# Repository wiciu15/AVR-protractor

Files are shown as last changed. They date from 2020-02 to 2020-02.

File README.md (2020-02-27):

# AVR-protractor
ATMega8 based protractor with SSD1306 OLED and LIS3DH accelerometer.

Schematic and PCB made in KiCAD. Firmware project created in Atmel Studio 7. Makefile available.

Known issue - ISP header is flipped, don't try to connect it to AVRISP with kanda ribbon cable, it's gonna make a short.

Firmware is working, but some extra features are still WIP (@TODO in main.c)

Display driver made by @tibounise (https://github.com/tibounise/SSD1306-AVR) slightly modified by me to save RAM for framebuffer.

3d front

3d PCB

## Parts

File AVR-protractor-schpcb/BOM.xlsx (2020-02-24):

Source: | C:\Users\wiki1\Documents\kicad\Poziomica 1.0\Poziomica 1.0.sch
Date: | 2019-01-20 01:33
Tool: | Eeschema (5.0.2)-1
Generator: | C:\Program Files\KiCad\bin\scripting\plugins/bom_csv_grouped_by_value.py
Component Count: | 31
Collated Components:
Item | Qty | Reference(s) | Value | LibPart | Footprint | zamowiony | kupiony | doszedl | Cena/szt | Cena/PCB
1 | 1 | AC1 | LIS3DHTR | SamacSys_Parts:LIS3DHTR | SSD1306:LIS3DH | kamami | 1.00 | 1.00 | 4.90 | 4.90 zł
2 | 1 | BT1 | Battery | Device:Battery | SSD1306:1021BatteryAAA | allegro-sm | 1.00 |  | 3.00 | 3.00 zł
3 | 2 | C1, C2 | 12pF | Device:CP_Small | Capacitor_SMD:C_0805_2012Metric_Pad1.15x1.40mm_HandSolder | allegro-sm | 1.00 |  | 0.05 | 0.10 zł
4 | 8 | C3, C4, C5, C6, C7, C8, C9, C10 | 2,2uF | Device:CP_Small | Capacitor_SMD:C_0805_2012Metric_Pad1.15x1.40mm_HandSolder | allegro-sm | 1.00 |  | 0.05 | 0.40 zł
5 | 2 | C11, C12 | .1uF | Device:CP_Small | Capacitor_SMD:C_0603_1608Metric_Pad1.05x0.95mm_HandSolder | allegro-sm | 1.00 |  | 0.05 | 0.10 zł
6 | 2 | C13, C14 | 10uF | Device:CP_Small | Capacitor_SMD:C_0805_2012Metric_Pad1.15x1.40mm_HandSolder | allegro-sm | 1.00 |  | 0.05 | 0.10 zł
7 | 1 | CON1 | SSD 1306 OLED | SSD1306:OLED | SSD1306:SSD1306 | allegro artronic | 1.00 | 1.00 | 19.40 | 19.40 zł
8 | 1 | IC1 | MCP1623T-I_CHY | SamacSys_Parts:MCP1623T-I_CHY | SamacSys_Parts:SOT95P270X145-6N | tme | 1.00 | 1.00 | 2.16 | 2.16 zł
9 | 1 | J1 | Conn_02x05_Odd_Even | Connector_Generic_MountingPin:Conn_02x05_Odd_Even_MountingPin | SSD1306:PROG | w domu | 1.00 | 1.00 | 0.30 | 0.30 zł
10 | 1 | L1 | DLG-0403-4R7 | Device:L | SSD1306:IND-B82462G4 | allegro-sm | 1.00 |  | 2.46 | 2.46 zł
11 | 4 | R1, R2, R3, R4 | 10k | Device:R | Resistor_SMD:R_0805_2012Metric_Pad1.15x1.40mm_HandSolder | allegro-sm | 1.00 |  | 0.05 | 0.20 zł
12 | 1 | R5 | 120k | Device:R_Small | Resistor_SMD:R_1206_3216Metric_Pad1.42x1.75mm_HandSolder | allegro-sm | 1.00 |  | 0.05 | 0.05 zł
13 | 1 | R6 | 820k | Device:R | Resistor_SMD:R_0805_2012Metric_Pad1.15x1.40mm_HandSolder | allegro-sm | 1.00 |  | 0.05 | 0.05 zł
14 | 1 | R7 | 470k | Device:R | Resistor_SMD:R_0805_2012Metric_Pad1.15x1.40mm_HandSolder | allegro-sm | 1.00 |  | 0.05 | 0.05 zł
15 | 1 | SW1 | PWR | Switch:SW_Push | SamacSys_Parts:7914J1000E | allegro-sm | 1.00 |  | 1.23 | 1.23 zł
16 | 1 | SW2 | ZERO | Switch:SW_Push | SamacSys_Parts:7914J1000E | allegro-sm | 1.00 |  | 1.23 | 1.23 zł
17 | 1 | U1 | ATmega8A-AU | MCU_Microchip_ATmega:ATmega8A-AU | Package_QFP:TQFP-32_7x7mm_P0.8mm | allegro-artronic | 1.00 | 1.00 | 4.50 | 4.50 zł
18 | 1 | Y1 | Crystal | Device:Crystal | SSD1306:Crystal_HC49-U_Vertical | allegro-artronic | 1.00 | 1.00 | 0.50 | 0.50 zł
 |  |  |  |  |  |  |  |  |  | 40.73 zł

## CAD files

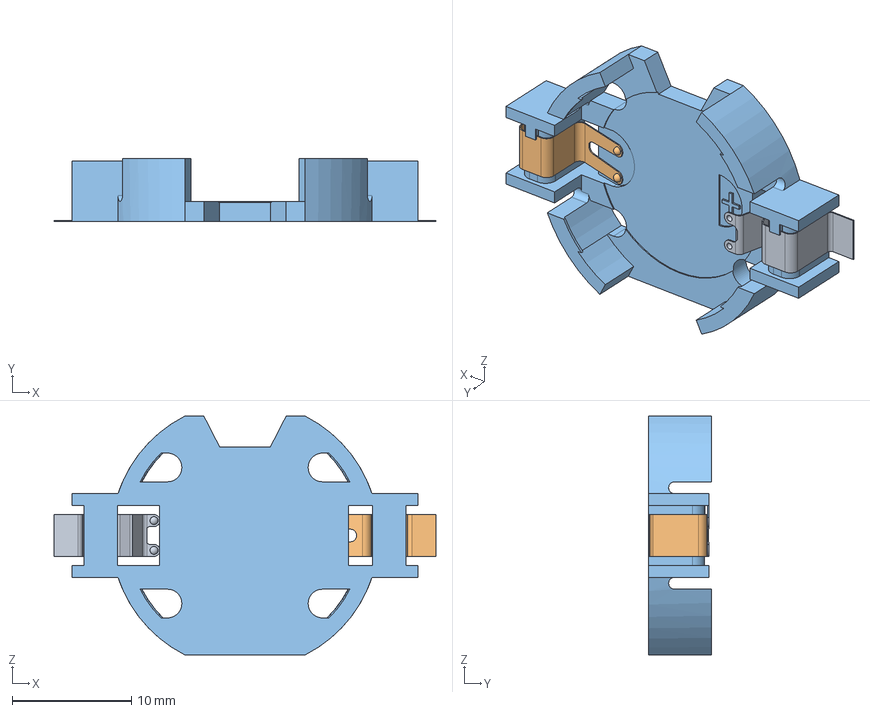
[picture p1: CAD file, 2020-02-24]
AVR-protractor-schpcb/CR2032/BU2032SM-HD-GCR2032 Battery Holder.stp
32.0 x 5.30 x 20.0 mm

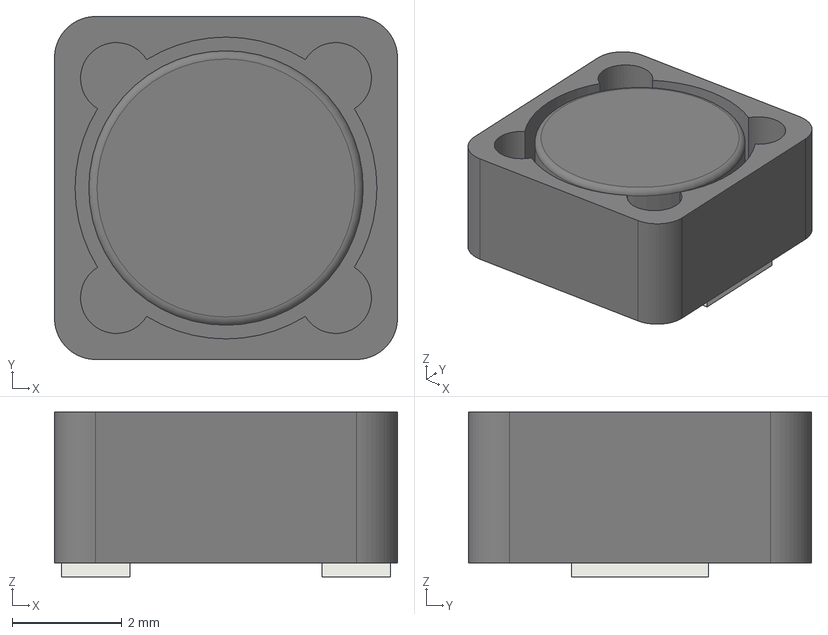
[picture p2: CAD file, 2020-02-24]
AVR-protractor-schpcb/L_Bourns_SRR1260 v1.step
6.25 x 6.25 x 3.00 mm

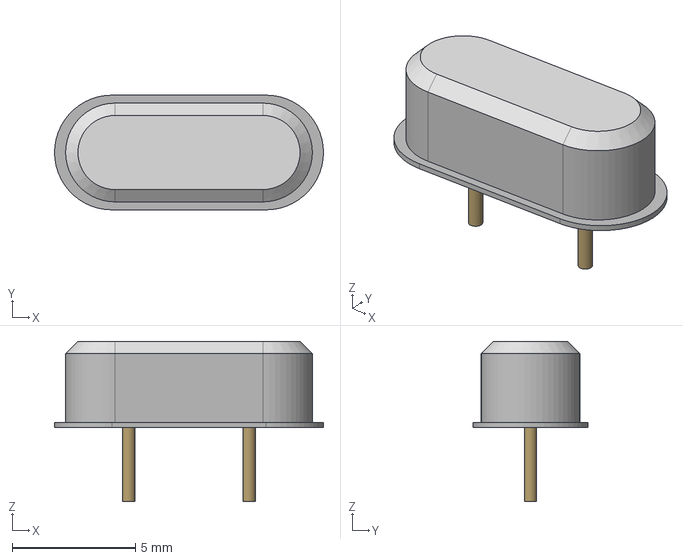
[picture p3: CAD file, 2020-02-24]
AVR-protractor-schpcb/Crystal_HC49-U_Vertical v2.step
10.9 x 4.65 x 6.50 mm

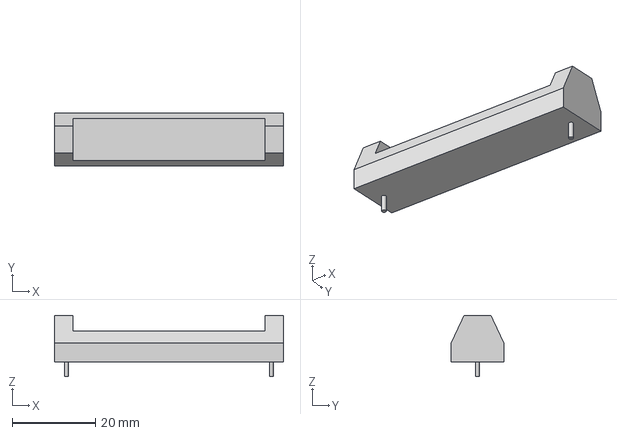
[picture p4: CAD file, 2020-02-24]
AVR-protractor-schpcb/Poziomica 1.0_battery v2.step
55.0 x 12.7 x 14.7 mm

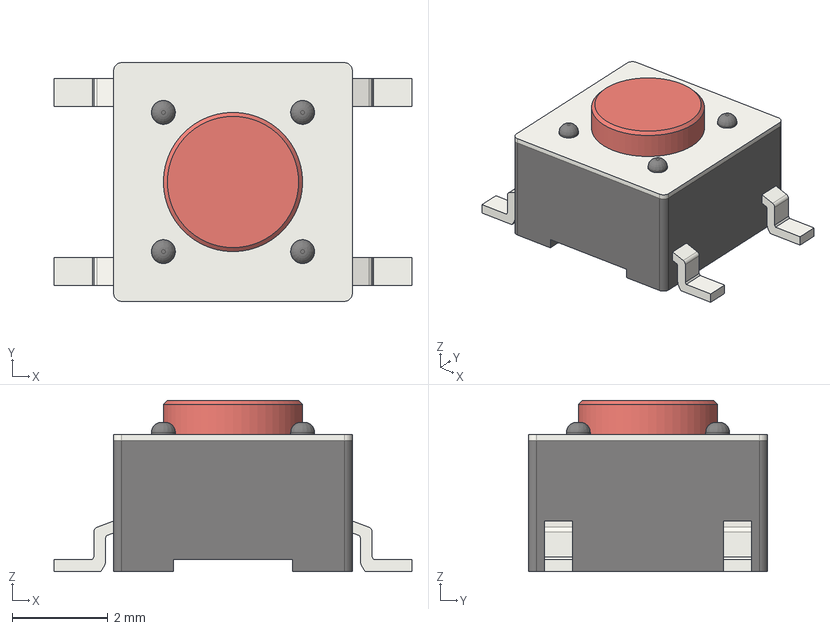
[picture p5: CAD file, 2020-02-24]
AVR-protractor-schpcb/SW_SPST_PTS645 v2.step
7.49 x 5.00 x 3.58 mm

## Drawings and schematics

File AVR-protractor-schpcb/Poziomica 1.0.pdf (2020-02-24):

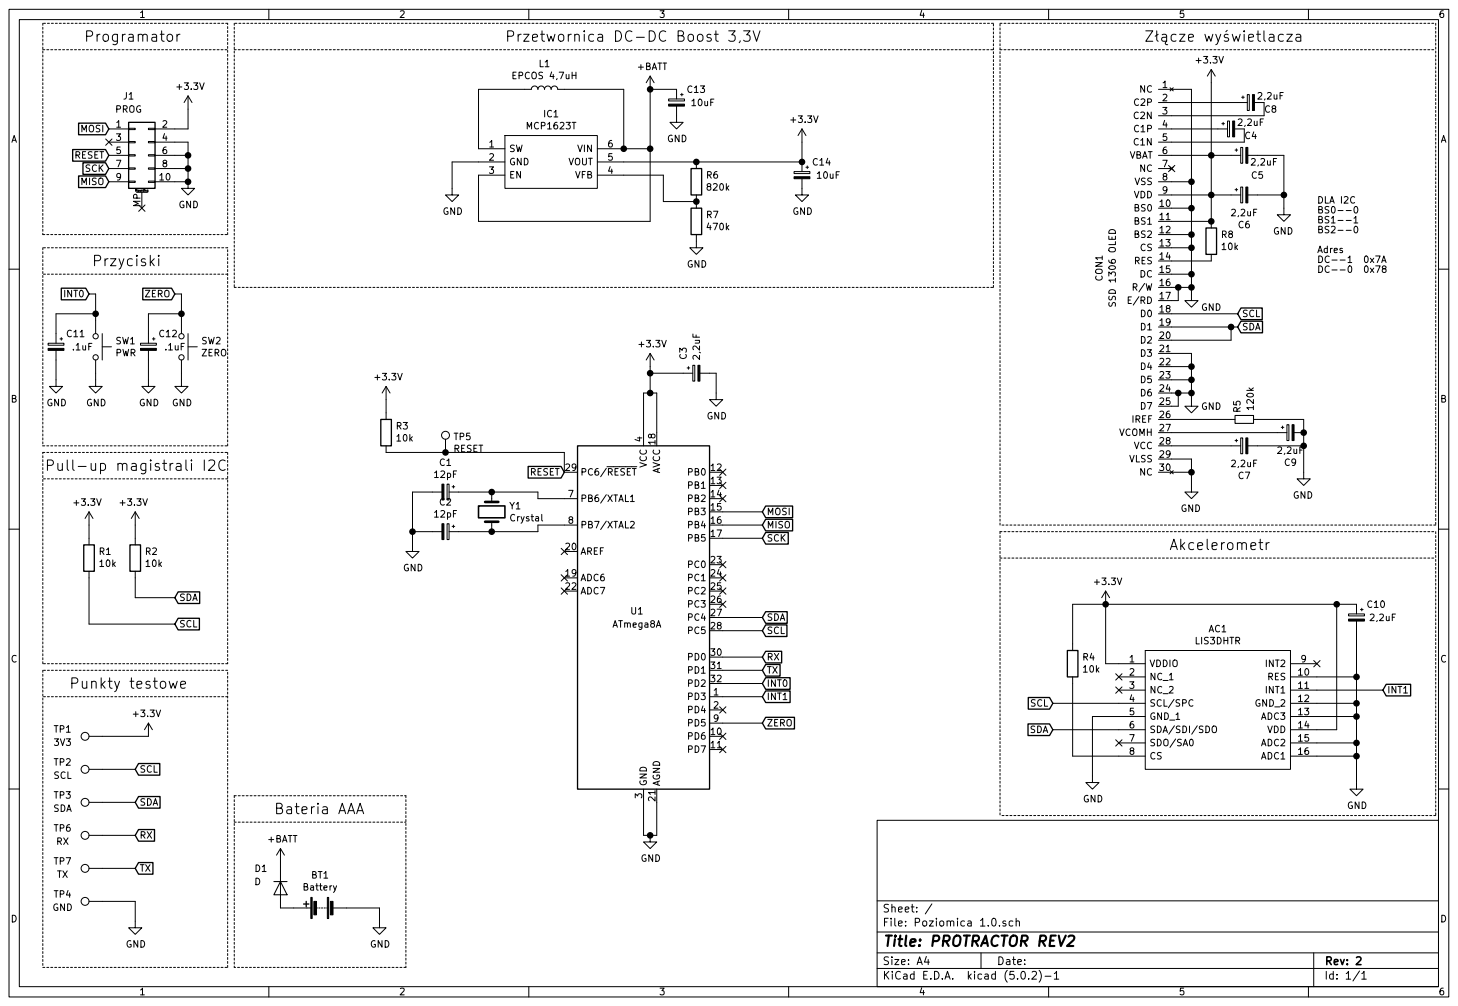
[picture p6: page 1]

Przetwornica DC-DC Boost 3,3V

NC 1 BS0 10 BS1 11 BS2 12 CS 13 RES 14 DC 15 R/W 16 E/RD 17 D0 18 D1 19 C2P 2 D2 20 D3 21 D4 22 D5 23 D6 24 D7 25
IREF 26 VCOMH 27 VCC 28 VLSS 29 C2N 3 NC 30 C1P 4 C1N 5 VBAT 6 NC 7 VSS 8 VDD 9 CON1 SSD 1306 OLED
Adres DC--1 0x7A DC--0 0x78 GND

J1 PROG MOSI RESET SCK MISO

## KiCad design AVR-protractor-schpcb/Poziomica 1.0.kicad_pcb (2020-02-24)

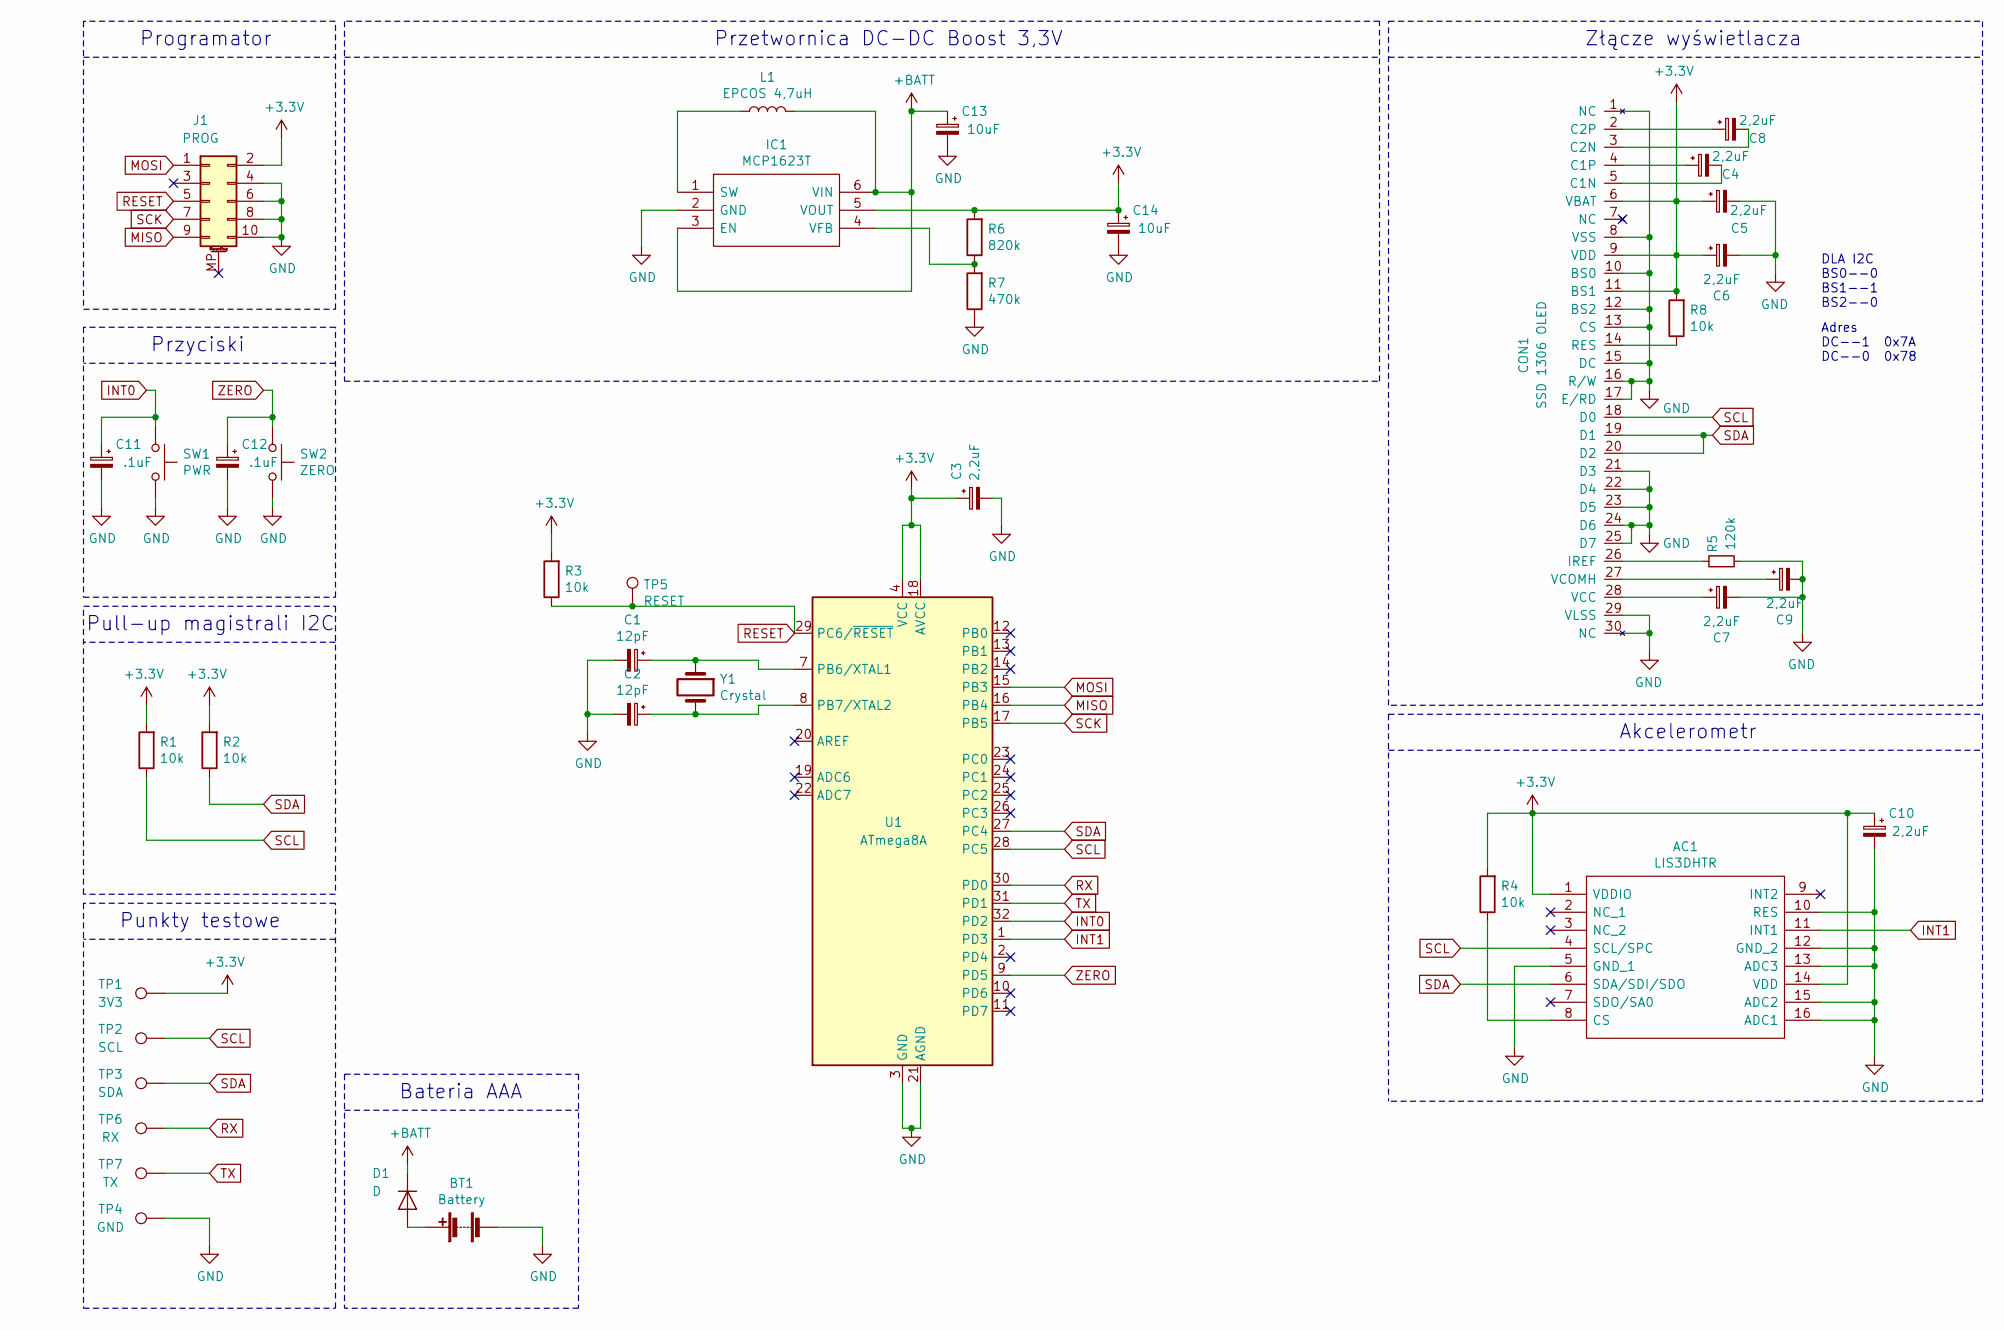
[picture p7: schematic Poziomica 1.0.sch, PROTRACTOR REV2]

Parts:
AC1: LIS3DHTR; LIS3DH_BigPad; Mouser Part Number 511-LIS3DHTR
BT1: Battery; 1021BatteryAAA
C1, C2: 12pF; C_0805_2012Metric_Pad1.15x1.40mm_HandSolder
C3, C4, C5, C6, C7, C8, C9, C10: 2,2uF; C_0805_2012Metric_Pad1.15x1.40mm_HandSolder
C11, C12: .1uF; C_0603_1608Metric_Pad1.05x0.95mm_HandSolder
C13, C14: 10uF; C_0805_2012Metric_Pad1.15x1.40mm_HandSolder
CON1: SSD 1306 OLED; SSD1306
D1: D; D_SOT-23_ANK
IC1: MCP1623T; SOT95P270X145-6N; Mouser Part Number 579-MCP1623T-I/CHY
J1: PROG
L1: EPCOS 4,7uH; IND-B82462G4
R1, R2, R3, R4, R8: 10k; R_0805_2012Metric_Pad1.15x1.40mm_HandSolder
R5: 120k; R_1206_3216Metric_Pad1.42x1.75mm_HandSolder
R6: 820k; R_0805_2012Metric_Pad1.15x1.40mm_HandSolder
R7: 470k; R_0805_2012Metric_Pad1.15x1.40mm_HandSolder
SW1: PWR; 7914J1000E
SW2: ZERO; 7914J1000E
TP1: 3V3; TestPoint_Pad_D2.0mm
TP2: SCL; TestPoint_Pad_D2.0mm
TP3: SDA; TestPoint_Pad_D2.0mm
TP4: GND; TestPoint_Pad_D2.0mm
TP5: RESET; TestPoint_Pad_D2.0mm
TP6: RX; TestPoint_Pad_D2.0mm
TP7: TX; TestPoint_Pad_D2.0mm
U1: ATmega8A; TQFP-32_7x7mm_P0.8mm
Y1: Crystal; Crystal_HC49-U_Vertical

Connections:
+3V3: AC1.1 (VDDIO), AC1.14 (VDD), C3.1, C5.1, C6.1, C10.1, C14.1, CON1.6 (VBAT), CON1.9 (VDD), CON1.11 (BS1), IC1.5 (VOUT), J1.2, R1.2, R2.2, R3.2, R4.2, R6.2, R8.2, TP1.1, U1.4 (VCC), U1.6 (VCC), U1.18 (AVCC)
+BATT: C13.1, D1.1 (K), IC1.3 (EN), IC1.6 (VIN), L1.2
GND: AC1.5 (GND_1), AC1.10 (RES), AC1.12 (GND_2), AC1.13 (ADC3), AC1.15 (ADC2), AC1.16 (ADC1), BT1.2 (-), C1.2, C2.2, C3.2, C5.2, C6.2, C7.2, C9.2, C10.2, C11.2, C12.2, C13.2, C14.2, CON1.1 (NC), CON1.8 (VSS), CON1.10 (BS0), CON1.12 (BS2), CON1.13 (CS), CON1.15 (DC), CON1.16 (R/W), CON1.17 (E/RD), CON1.21 (D3), CON1.22 (D4), CON1.23 (D5), CON1.24 (D6), CON1.25 (D7), CON1.29 (VLSS), CON1.30 (NC), IC1.2 (GND), J1.4, J1.6, J1.8, J1.10, R5.1, R7.1, SW1.2, SW2.2, TP4.1, U1.3 (GND), U1.5 (GND), U1.21 (AGND)
INT0: C11.1, SW1.1, U1.32 (PD2)
INT1: AC1.11 (INT1), U1.1 (PD3)
MISO: J1.9, U1.16 (PB4)
MOSI: J1.1, U1.15 (PB3)
unnamed: AC1.8 (CS), R4.1
unnamed: BT1.1 (+), D1.2 (A)
unnamed: C1.1, U1.7 (PB6/XTAL1), Y1.1
unnamed: C2.1, U1.8 (PB7/XTAL2), Y1.2
unnamed: C4.1, CON1.4 (C1P)
unnamed: C4.2, CON1.5 (C1N)
unnamed: C7.1, CON1.28 (VCC)
unnamed: C8.1, CON1.2 (C2P)
unnamed: C8.2, CON1.3 (C2N)
unnamed: C9.1, CON1.27 (VCOMH)
unnamed: CON1.14 (RES), R8.1
unnamed: CON1.26 (IREF), R5.2
unnamed: IC1.1 (SW), L1.1
unnamed: IC1.4 (VFB), R6.1, R7.2
RESET: J1.5, R3.1, TP5.1, U1.29 (PC6/~RESET)
RX: TP6.1, U1.30 (PD0)
SCK: J1.7, U1.17 (PB5)
SCL: AC1.4 (SCL/SPC), CON1.18 (D0), R1.1, TP2.1, U1.28 (PC5)
SDA: AC1.6 (SDA/SDI/SDO), CON1.19 (D1), CON1.20 (D2), R2.1, TP3.1, U1.27 (PC4)
TX: TP7.1, U1.31 (PD1)
ZERO: C12.1, SW2.1, U1.9 (PD5)

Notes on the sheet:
DLA I2C BS0--0 BS1--1 BS2--0
Złącze wyświetlacza
Akcelerometr
Punkty testowe
Pull-up magistrali I2C
Przyciski
Programator
Bateria AAA
Przetwornica DC-DC Boost 3,3V
Adres DC--1 0x7A DC--0 0x78

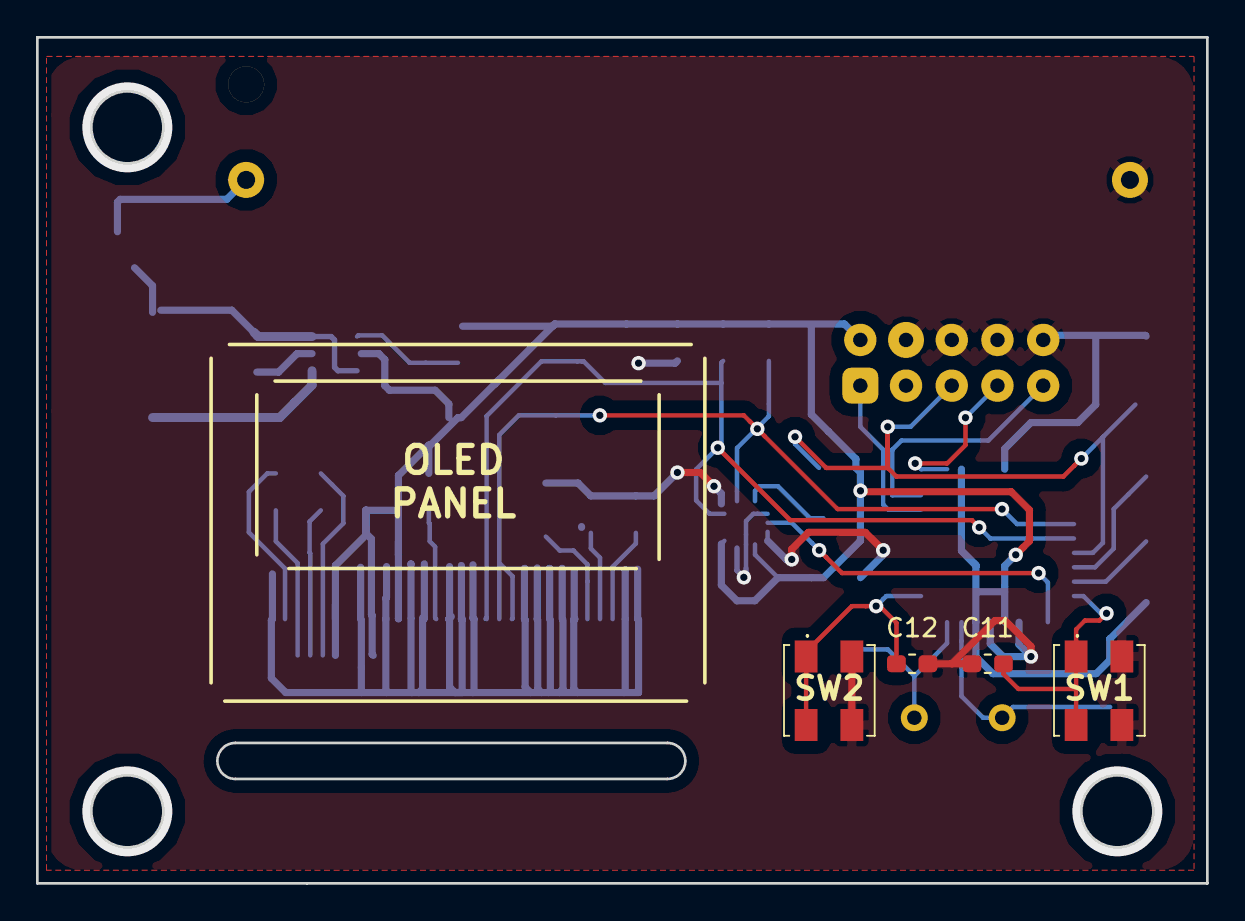
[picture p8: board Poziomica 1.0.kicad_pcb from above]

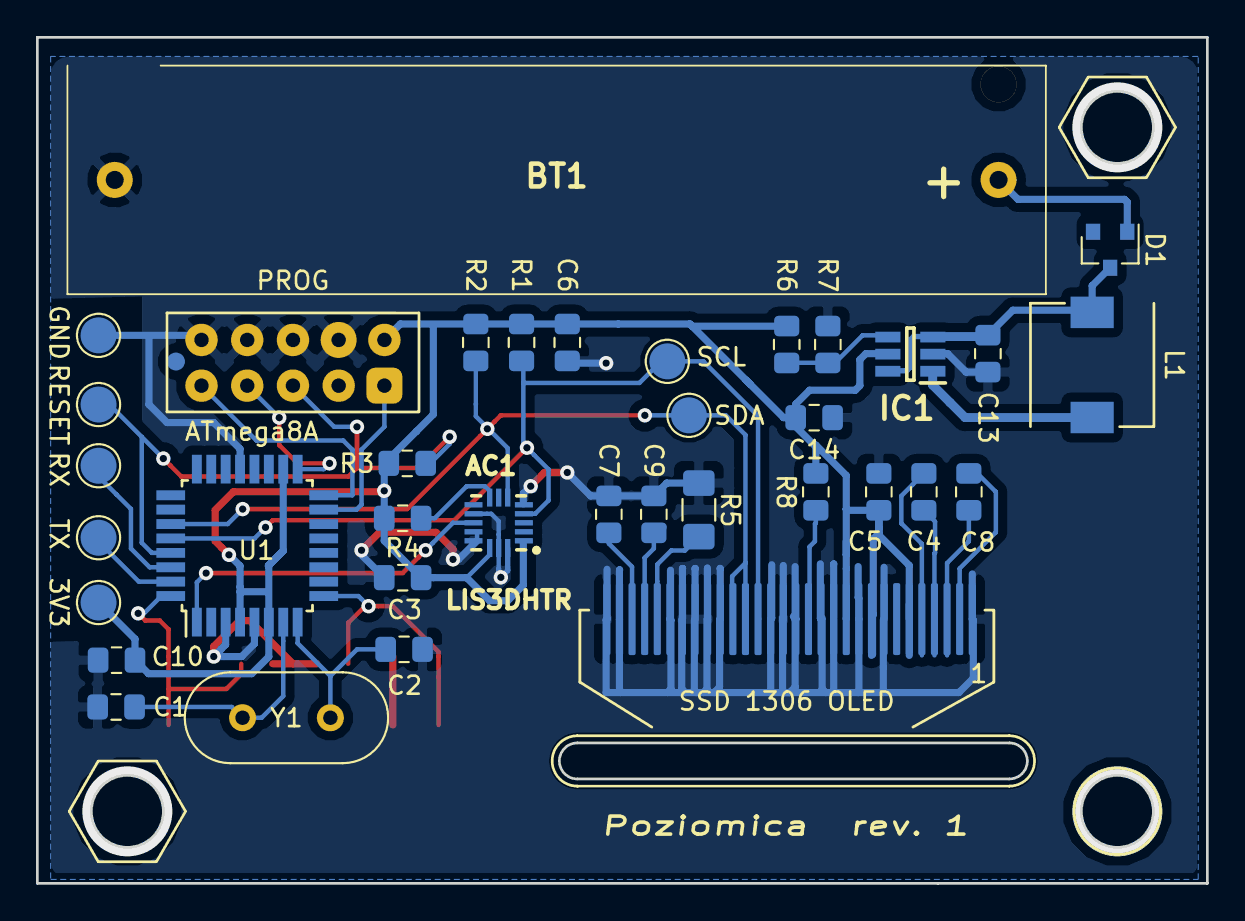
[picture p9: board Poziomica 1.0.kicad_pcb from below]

Board: 2 copper layers, 65.0 x 47.0 mm, 40 parts (36 on the bottom side), 28 nets.

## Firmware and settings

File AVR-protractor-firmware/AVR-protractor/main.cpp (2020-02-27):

/*
 //////////////////////////////////////
 ///       AVR-protractor rev1       //
 //////////////////////////////////////
Created: 21.02.2019 15:53:35
Author : Wiktor Burdecki

Debug data on UART, baud 38400, 8bits/1stop

Screen is divided to 2 areas -  left and right which are drawn separately but share a 512b framebuffer in RAM
Full framebuffer is unachievable because ATMega 8A has 1kB of RAM, and framebuffer needs 128*64 bits =1024B
Left side is dedicated for graphic representation of orientation
Right side is drawing numeric values

Graphics library is a modified https://github.com/tibounise/SSD1306-AVR library by tibounise. Changes were made mainly to sendFramebuffer function. I also added contrast control.

		@TODO
	*implement font drawing
	*enhance UI design
	*expand LIS3DH library functionalities
	*add support for buttons and interrupt from accelerometer
	*standby mode and wake-up with external interrupt
	*UART rx functionality and implementing configuration commands
 */ 

#include <avr/io.h>
#include <stdint.h>
#include <util/delay.h>
#include <stdio.h>
#include <math.h>
#include <stdlib.h>

#include "USART.h"
#include "SSD1306.h"
#include "I2C.h"
#include "LIS3DH.h"
#include "Framebuffer.h"

float pitch=0.0; //averaged and calculated angle values
float roll=0.0;
float yaw=0.0;

int32_t sumX=0; //sum of few acc readings
int32_t sumY=0;
int32_t sumZ=0;

int16_t oneX=0; //one acceleration reading from axis
int16_t oneY=0;
int16_t oneZ=0;

float rollOffset=0; //offset to correct angle value static error
float pitchOffset=0;
float yawOffset=0;

uint8_t n=0; //samples counter
uint8_t samplesToAvg=10;  //number of samples to calculate average

uint8_t measurementMode=0; //0 for laying on back, 1 for laying on side

	

int main(void)
{
	SSD1306 disp;
	LIS3DH acc;
	Framebuffer fb;
	
	
	USART_Init(25); //25 for 16MHz crystal and 38400 baud (0,2% error)
	fb.clear();	
	fb.show(0);
	fb.show(1);
	
     
    while (1) 
    { 
		_delay_ms(10);//screen refresh rate is delay*samplesToAvg
		
		//////////////////////////////////////////////////////////////////get reading from acc and add it to a sum
		 oneZ = acc.readAcc(OUT_Z_L,OUT_Z_H);
		 oneY= acc.readAcc(OUT_Y_L,OUT_Y_H);
		 oneX = acc.readAcc(OUT_X_L,OUT_X_H);
		 sumZ+=oneZ; 
		 sumY+=oneY; 
		 sumX+=oneX; 
		 n++;
		 
		 if(n==samplesToAvg-1){
			//////////////////////////////////////////////////////////////////calculate average acc reading
			int16_t Xavg=sumX/samplesToAvg;
			int16_t Yavg=sumY/samplesToAvg;
			int16_t Zavg=sumZ/samplesToAvg;
						 
			//reset values
			n=0; sumZ=0; sumY=0; sumX=0;
			
			//////////////////////////////////////////////////////////////////calculate angles
			//https://www.digikey.com/en/articles/techzone/2011/may/using-an-accelerometer-for-inclination-sensing
			
			pitch= ((atan2(Xavg, sqrt(square(Yavg) + square(Zavg)))*180.0)/M_PI)+pitchOffset;
			roll = ((atan2(Yavg, sqrt(square(Zavg) + square(Xavg)))*180.0)/M_PI)+rollOffset;
			yaw = ((atan2(sqrt(square(Yavg) + square(Xavg)), Zavg)*180.0)/M_PI)+yawOffset;
			//////////////////////////////////////////////////////////////////change angle display mode depending on device orientation
			//between 40 and 70 degrees stays in last set mode (hysteresis to prevent from fast changes of display mode)
			if(abs(roll)>70){
				measurementMode=1; //on side
			}
			if(abs(roll)<40){
				measurementMode=0; //on back
			}
			
			//////////////////////////////////////////////////////////////////WRITE VALUES TO UART
			USART_WriteDebug(pitch,roll,yaw,measurementMode);
			
			//////////////////////////////////////////////////////////////////DRAW LEFT HALF OF SCREEN
			//sine is used to move a dot faster around 0 degrees which is supposed to give extra accuracy of graphic
			fb.clear();
			if(!measurementMode){
			fb.drawRectangle(28,28,36,36);
			fb.drawPixel((int8_t)(sin(pitch*M_PI/180)*32)+32,(sin(roll*M_PI/180)*32)+32);
			}else{
				fb.drawHLine(16,1,63);
				fb.drawPixel((int8_t)(sin(pitch*M_PI/180)*32)+32,30);
			}
			fb.show(0);//draw framebuffer on left side of screen
		 
			//////////////////////////////////////////////////////////////////DRAW RIGHT HALF OF SCREEN	
			fb.clear();
			fb.show(1);//draw framebuffer on right side of screen
			}
		 
    }
}

 

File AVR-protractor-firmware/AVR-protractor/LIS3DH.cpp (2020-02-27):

/*
 * CPPFile1.cpp
 *
 * Created: 27.02.2019 12:52:34
 *  Author: wiki1
 */ 

#include "I2C.h"
#include "LIS3DH.h"

#include <avr/io.h>
#include <stdint.h>

 LIS3DH::LIS3DH (){
	i2c_acc_w.init(LIS3_ADRESS_W);
	i2c_acc_r.init(LIS3_ADRESS_R);
	sendCmd(CTRL_REG1,0b00110111);
}

 void LIS3DH::sendCmd(uint8_t reg , uint8_t data){

	i2c_acc_w.start();
	i2c_acc_w.write(reg);
	i2c_acc_w.write(data);
	i2c_acc_w.stop();

}

uint8_t LIS3DH::readReg(uint8_t reg){
	uint8_t data;
	i2c_acc_w.start();
	i2c_acc_w.write(reg);
	i2c_acc_w.stop();
	
	i2c_acc_r.start();
	data=i2c_acc_r.readAck();
	i2c_acc_r.stop();
	return data;
	
}

int16_t LIS3DH::readAcc(uint8_t regLow, uint8_t regHi){
	int8_t dataH;
	int16_t data;
		
	data= readReg(regLow);
	dataH= readReg(regHi);
	data|=dataH<<8;
	return data;
}

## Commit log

2020-02-24 added 1-axis bubble mode when device is on the side
2020-02-27 added defines for accelerometer registers
